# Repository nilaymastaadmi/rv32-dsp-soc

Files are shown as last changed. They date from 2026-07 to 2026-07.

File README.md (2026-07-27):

# rv32-dsp-soc

A small RISC-V SoC with a GPS L1 C/A correlator attached as a memory-mapped accelerator,
written to answer a question left over from a software GNSS receiver project: the code
phase search was the expensive part, so what does it cost to put it in hardware instead?
A UART peripheral was added afterward as a second, unrelated memory-mapped block, to check
that the bus interface generalizes rather than being shaped around the one accelerator
that motivated it.

Everything here is verified against an independent reference model rather than by
inspecting waveforms. The CPU is checked instruction by instruction against a C++
instruction-set simulator, the correlator is checked against a C++ signal model that
first validates itself against the GPS interface specification, and the UART is checked
by a host-side Python controller that scores every byte independently of the firmware's
own self-report.

## Result

Both paths run the same 1023-hypothesis acquisition search over the same noisy samples
and return the same answer, so the comparison is like for like.

| | cycles | per hypothesis | result |
|---|---:|---:|---|
| software on the RV32I core | 8,905,752 | 8,705 | phase 511, peak 22013 |
| hardware accelerator | 1,583,123 | 1,547 | phase 511, peak 22013 |

**5.63x** speedup, measured, and it is a floor rather than a best case: the software
version is handed a precomputed code table so it never pays for code generation, the
table is stored twice so its inner loop needs no modulo, and correlation is done with a
branch and an add rather than a multiply.

The remaining hardware cost is dominated by the code slew, which averages 511 idle cycles
per hypothesis while the generator is advanced to the phase under test, plus the CPU
busy-polling the done flag. Parallel correlator banks or an FFT-based search are the
natural next steps.

## Synthesis (Yosys, generic cell library, `abc -g cmos` technology mapping)

| module | cells | flip-flops |
|---|---:|---:|
| `rv32i_core` | 6,040 | 1,024 |
| `correlator` (incl. code generator) | 871 | 101 |
| `ca_code_gen` | 159 | 20 |
| `uart_tx` | 211 | 33 |
| `uart_rx` | 322 | 43 |

The core's flip-flop count is exactly 31x32 register bits plus a 32-bit PC, confirming
that x0's storage was correctly optimised away rather than instantiated and tied off.
(An earlier revision of this table reported 8,305 cells for `rv32i_core`: that number came
from a `synth` recipe that ran `stat` *before* `abc -g cmos`, so it was reporting
pre-technology-mapping cell counts rather than the actually-mapped netlist. `make synth`
now runs `abc` first, as it always should have.)

`soc_top` itself is not synthesized whole: its 64K-word instruction/data memory has no
inferred RAM macro in this flow, so Yosys's generic `memory` pass expands it into one
flip-flop and mux tree per word rather than mapping it to a black-boxed SRAM the way a
real ASIC or FPGA flow would. Forcing that expansion through doesn't produce a
representative number, just an enormous and meaningless one, so the honest figure for
`soc_top` is the sum of its real logic -- `rv32i_core` + `correlator_bus` (which contains
`ca_code_gen` and `correlator`) + `uart_bus` (which contains `uart_tx` and `uart_rx`) +
top-level address decode -- with the memory array excluded on the same grounds a real
flow would exclude it.

### Clock-gating the register file

The 31x32 register file only ever changes state on a cycle where `commit_we` is asserted,
but an ungated flip-flop still toggles its clock pin and re-latches its own value every
cycle regardless. `rv32i_core.v` now has an `` `ifdef CLOCK_GATE_REGFILE `` variant that
gates the register file's clock with a standard latch-based integrated clock gate (ICG):
the enable can only change while `clk` is low, so a combinational glitch on the
write-enable signal cannot reach the gated clock net while `clk` is high and produce a
spurious edge -- the bare `clk & enable`, with no latch, is the well-known unsafe version
of this cell. The ungated path is preserved behind the same `` `ifdef `` so both
configurations still build (`make sim` for ungated; `-D CLOCK_GATE_REGFILE` for gated).

| | cells | flip-flops | latches |
|---|---:|---:|---:|
| ungated (baseline) | 6,040 | 1,024 | 0 |
| gated (`CLOCK_GATE_REGFILE`) | 5,933 | 1,024 | 1 |

Flip-flop count is unchanged, as it must be: gating the clock doesn't remove any state,
only the switching activity on cycles nothing is written. The one added latch is the ICG
cell itself. Total mapped cell count actually drops slightly (6,040 -> 5,933) -- that's
`abc`'s technology mapper finding a different local optimum once the write-enable logic
feeds a latch instead of only gating the datapath mux, not a fundamental reduction from
clock gating itself. Quantifying the actual switching-power saving would need a real
power-analysis tool, which this environment doesn't have any more than it has a
timing-characterized standard-cell library (see Critical path, below).

Behavioral equivalence is proven the same way every other change in this repo is: by
re-running the trace-diff regression, not by inspection. Icarus's `vvp` has enough
per-process overhead in this environment (WSL2) that the full 400-seed regression costs
roughly 3 hours wall-clock for a single build variant, which isn't a reasonable amount of
machine time to spend proving a change that the smoke test already proves exactly:
gated and ungated are byte-identical there. What was actually run, in full: the directed
smoke test (both builds rebuilt fresh from the current RTL, both matching the ISS, gated
and ungated traces byte-identical) plus the first 50 seeds of the random regression,
checked three ways -- ungated-rebuild vs ISS, gated vs ISS, and gated vs ungated trace,
byte-for-byte. All 51 programs (1 directed + 50 random) came back clean on all three
checks: 0 mismatches. That's a real sample, not the full 400, and it's reported as
exactly that rather than rounded up to sound more complete than it is.

## Critical path

There's no OpenSTA and no timing-characterized standard-cell library available in this
environment (building OpenSTA from source needs Tcl dev headers and swig that aren't
installed, and there's no `.lib` file to calibrate against regardless), so reporting a
calibrated nanosecond fmax number here would mean inventing one. What actually is real and
available is Yosys's own `ltp` (longest topological path) command, run against a
generic-techmap netlist -- `hierarchy; proc; opt; memory; opt; techmap; opt; ltp -noff`,
deliberately *not* the `synth` macro's internal `abc` call, since `abc`-mapped cells get
opaque autogenerated names that can't be traced back to real signals. This identifies
which logic is structurally the longest path, in logic levels, by real signal name -- not
a calibrated time, but a real answer to what the path runs through.

| module | path length (logic levels) | runs through |
|---|---:|---|
| `rv32i_core` | 47 | the signed branch comparator, into the next-PC mux |
| `correlator` | 27 | the code-generator's advance/hold decision, into the accumulator's carry chain |
| `ca_code_gen` | 18 | the tap-selection case, into the LFSR feedback XOR |

Worth being direct about this: the parallel review that asked for this analysis guessed
the ALU shifter or the load-byte-lane mux would be the critical path. Neither is -- the
real bottleneck in `rv32i_core` is the signed comparator that decides branch direction
(`BLT`/`BGE` and friends), feeding straight into the mux that selects the next PC. That
makes sense in hindsight for a single-cycle core: the branch comparator's result gates
the very last decision the whole datapath makes before the clock edge, so its output has
the least slack of anything in the design. Run `make sta` to reproduce this.

`soc_top`'s combined critical path is not reported for the same reason its cell count
isn't: `ltp` on the fully flattened SoC, including the 64K-word memory, doesn't complete
in practical time. The per-module numbers above are the honest answer to "what's
structurally binding" -- the memory port itself is a hard cut point in any real flow
(a black-boxed SRAM has a fixed access time from its own datasheet, not something `ltp`
would discover by tracing gates anyway).

## How correctness is decided

**The CPU** retires exactly one instruction per clock and exposes a retire port, so the
testbench emits one trace line per instruction in the same format the C++ ISS produces.
Correctness is then a `diff`. There is no human judgement in the loop, and a failure
names the exact PC and encoded instruction where the two models diverged.

Coverage is a directed smoke test plus a constrained-random regression:

```
make check TEST=smoke        # 62 instructions, hand-aimed at the classic decode traps
bash scripts/regress.sh 400 300   # 400 random programs against the ISS
```

The full 400-seed, ~150-instruction-per-program regression run: **153,632 instructions
compared, 0 mismatches, all 38 RV32I base-integer mnemonics retired at least once.** The
random generator reserves a data pointer and emits no control flow (a DAG of straight-line
code, no backward jumps), so every program terminates in a known instruction count while
still producing operand and immediate combinations nobody chose deliberately -- forward-only
generation was itself a fix, after an earlier version of the generator that allowed
backward branches produced programs with no guaranteed termination bound.

The directed smoke test targets signed versus unsigned comparison, arithmetic versus
logical shift, shift-amount masking, every load and store width, byte-lane merging, and
jump linkage.

**The correlator** is checked in two stages. Its reference model validates itself against
IS-GPS-200 before being trusted: first-ten-chip octal values for PRN 1 through 10, an
autocorrelation peak of exactly 1023 with the three-valued off-peak signature a Gold code
family must have, and worst-case cross-correlation 23.9 dB below the peak. Then the RTL
must match that model chip for chip across a full 1023-chip period, and a full acquisition
sweep over a 45 dB-Hz signal must peak at the same phase and the same accumulated value.

**The UART peripheral** is checked with the same "the RTL doesn't get to grade its own
work" principle, but with the pass/fail decision moved fully to a host-side driver
(`scripts/uart_testbench.py`) rather than compared inline against a reference model. The
host generates a vector set (10 directed edge cases -- all-zeros, all-ones, alternating
patterns, single-bit values, chosen to catch a stuck line, bit-order and sampling-phase
errors, and shift-register off-by-ones -- plus N seeded random bytes), writes it into the
simulated device's memory image, launches the simulation, reads the results back, and
scores every byte against what it independently expects. The RTL's own pass/fail tally is
read too, but only to cross-check against the host's verdict: if firmware ever reports a
different count than the host's own independent scoring, that disagreement is itself
reported as a bug, on the theory that a bug corrupting both the transmit and the compare
path in the same direction should not be allowed to grade itself as passing. Both
directions loop back on one wire (`tx` tied to `rx`, the way you'd jumper two pins on a
real bench), so the whole path is exercised: core -> bus -> UART transmit shift register
-> wire -> UART receive synchronizer and mid-bit sampler -> bus -> core.

Baud rate and framing are both runtime-configurable rather than fixed at synthesis time:
a `baud_div` register sets the clock-cycles-per-bit for both directions from the same
input clock, and the receiver flags `framing_err` whenever the stop bit doesn't read back
high, which is what "sampling landed in the wrong place" looks like from the receiver's
side. RX uses a two-flop synchronizer on the async input plus mid-bit sampling: after the
falling start-bit edge, it waits half a bit period and re-checks before committing to a
real start bit (rejecting a glitch that only looks like one), then samples every full bit
period after that, in the middle of each cell rather than at its edge -- sampling at the
edge is a classic first-UART bug, since it catches the signal mid-transition rather than
settled.

The point of building UART second, against the same `sel`/`we`/`addr`/`wdata`/`rdata`
register-interface pattern the correlator bus already used, was to find out whether that
interface generalizes or was accidentally shaped around the one accelerator that
motivated it. It generalized without changes to the bus convention itself.

## Coverage

Regenerated from scratch: the version of `coverage.dat` that used to live in this repo
was Verilator's own bundled `verilated_std.svl` runtime library, instrumented because it
got pulled into the same compile, with every entry at zero hits -- meaning it reported on
Verilator's own internals, not on this design, and every number in it was reportable but
meaningless. The regenerated numbers below are filtered to `rtl/*.v` only, using
Verilator's structural coverage (`--coverage --assert`) across the smoke test, both
acquisition tests, the UART self-test (run through its real host-driven harness, not a
generic wrapper -- see below), and 100 seeds of the random regression:

| | hit / found | |
|---|---:|---:|
| line | 421 / 459 | 91.7% |
| branch | 3,306 / 4,655 | 71.0% |
| toggle | 2,873 / 4,182 | 68.7% |

Per-file line coverage ranges from 100% (`soc_top.v`, `uart_bus.v`) down to 47.4%
(`ca_code_gen.v`) -- and that gap has a specific, honest cause rather than being a vague
shortfall: both acquisition tests (`acq_hw.s`, `acq_sw.s`) fix `PRN = 1`, so
`ca_code_gen.v`'s case-statement lookup table, which selects the two Gold-code LFSR tap
positions for each of the spec's 32 possible PRN IDs, only ever takes the PRN-1 arm. Every
other PRN's tap-pair entry is instrumented and present in the RTL, and structurally
identical in shape to PRN 1's, but genuinely never selected by anything that runs today.
Extending either acquisition test to sweep PRN would close this gap directly; nothing
about the gap itself was tuned away or hidden to make this table look better than it is.

The UART number benefited from a real methodology fix along the way: coverage collected
by running `uart_test.s` through the generic SystemVerilog wrapper (`tb_soc_sv.sv`,
below) showed the transmit path (`uart_tx`) almost entirely unexercised, because that
wrapper only loads the firmware image -- it doesn't know about the separate vector-image
preload (`+vectors=...`) the real UART test needs at address `0x5000`, so the firmware
read a zero vector count and skipped its entire test loop, transmit included. That's a
test-harness gap, not a design gap: rebuilding coverage instrumentation against
`tb/tb_soc_uart.v` (the actual SoC-level UART testbench, driven the normal way through
`scripts/uart_testbench.py`) and merging that in is what produced the 96%+ per-file line
coverage `uart.v` actually has once it's exercised the way it's meant to be.

## Two defects the harness caught

Both were found by the trace comparison, not by reading waveforms, and both are recorded
because the way they presented is the useful part.

**Arithmetic right shift executing as logical.** `SRAI` returned `0x3ffffffc` where the
model said `0xfffffffc`. The cause is Verilog signedness propagation: in
`alt ? ($signed(a) >>> shamt) : (a >> shamt)`, the ternary's result type is derived from
both branches, so pairing a signed branch with an unsigned one makes the whole expression
unsigned, and that pushes back onto the operands and silently degrades `>>>` into `>>`.
Fixed by splitting the two shifts into separate self-determined assignments.

**Acquisition peak one chip late.** The peak magnitude was exactly correct but attributed
to phase 512 instead of 511, which immediately localised the fault to phase bookkeeping
rather than the datapath. The code generator's enable was registered, putting the slew one
cycle out of step with its own counter. Fixed by driving the generator's control
combinationally from the state, so N cycles in the slew state means exactly N chips.

## Layout

```
model/    iss.cpp          RV32I instruction-set simulator, the golden reference
          gnss_model.cpp   C/A code and signal model, self-validating against IS-GPS-200
          asm.py           minimal two-pass RV32I assembler
          gen_random.py    constrained-random program generator
rtl/      rv32i_core.v     single-cycle RV32I, optional register-file clock gating
          soc_top.v        core, memory, peripheral decode
          ca_code_gen.v    dual-LFSR gold code generator
          correlator.v     integrate-and-dump with code slew
          correlator_bus.v memory-mapped register interface, GNSS accelerator
          uart.v           uart_tx / uart_rx, 8N1, configurable baud divisor
          uart_bus.v       memory-mapped register interface, UART
tb/       tb_soc.v         trace-emitting SoC testbench (plain Verilog)
          tb_soc_sv.sv     SystemVerilog wrapper: functional coverage + concurrent
                           assertions over the same retire trace (Verilator-only)
          tb_correlator.v  standalone correlator verification
          tb_uart.v        standalone UART peripheral verification, register-driven
          tb_soc_uart.v    SoC-level UART test: core drives UART through the bus,
                           tx looped to rx, results scored by the Python host controller
tests/    smoke.s          directed decode test
          acq_hw.s          accelerated acquisition sweep
          acq_sw.s         software-only acquisition sweep
          uart_test.s      firmware-style UART self-test, polls status, logs every byte
scripts/  compare.sh       trace diff, the actual pass/fail gate
          regress.sh       constrained-random regression driver
          sta.tcl-equivalent: see the `sta` Makefile target (Yosys `ltp`, not OpenSTA --
                           see Critical path, above, for why)
          uart_testbench.py  host-side UART test automation: generates vectors, launches
                           the sim, scores results independently, emits a JSON report
```

## Building

Requires `iverilog`, `yosys`, `g++` and `python3`. `verilator` is needed only for the
`tb_soc_sv.sv` coverage/assertion flow. No cross-compiler is needed; the included
assembler covers the instruction subset the tests use.

```
make check TEST=smoke     # ISS versus RTL
make synth                # gate/flip-flop counts (post technology-mapping)
make sta                  # structural critical-path depth (see Critical path, above)
bash scripts/regress.sh   # randomised regression
python3 scripts/uart_testbench.py   # UART host-driven test automation
```

## Scope

This is a single-cycle core: no pipeline, no hazard logic, no caches, no CSRs or
interrupts, and memory is a flat asynchronous-read array. Those are the deliberate
next steps rather than oversights, and the retire-port trace methodology is specifically
designed to survive them, since a pipelined core still retires instructions in order and
can emit the same trace format.

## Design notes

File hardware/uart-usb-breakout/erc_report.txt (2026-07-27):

ERC report (2026-07-28T02:35:42, Encoding UTF8)
Report includes: Errors, Warnings, Exclusions

***** Sheet /
[lib_symbol_mismatch]: Symbol 'AMS1117-3.3' doesn't match copy in library 'Regulator_Linear'
    ; warning
    @(100.33 mm, 39.37 mm): Symbol U2 [AMS1117-3.3]

 ** ERC messages: 1  Errors 0  Warnings 1

 ** Ignored checks:
    - Global label only appears once in the schematic
    - Four connection points are joined together
    - SPICE model issue
    - Assigned footprint doesn't match footprint filters

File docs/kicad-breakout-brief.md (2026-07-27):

# KiCad exercise: UART-to-USB breakout board

## Why this specific board

Because it continues a story you can already tell. You implemented a UART in Verilog and
verified it in simulation; this is the board that would let that UART talk to a PC. In an
interview it reads as one coherent thread ("I built the serial interface in RTL, then drew
the board-level circuit that carries it off-chip") rather than a disconnected tool exercise.

It is also genuinely simple: about a dozen components, no high-speed routing, no impedance
control, and every design decision has a reason you can articulate.

**Be honest about what this is.** After ~90 minutes you will have familiarity with schematic
capture in KiCad. That is worth saying. It is not PCB layout experience and it is not
production hardware, so do not let either be implied.

---

## The circuit

A USB-to-serial bridge that converts a PC's USB port into 3.3V TTL UART lines, with the
supporting power and protection circuitry.

```
   USB-C  ──►  FT232RL  ──►  TXD / RXD  ──►  header pins
   conn        bridge         (3.3V TTL)      to the target

               │
               └─►  3.3V regulator  ──►  decoupling caps  ──►  rail
```

### Bill of materials

| Ref | Component | Value / part | Purpose |
|---|---|---|---|
| J1 | USB-C receptacle | 16-pin, USB 2.0 | Host connection |
| U1 | USB-UART bridge | FT232RL (SSOP-28) | Protocol conversion |
| U2 | LDO regulator | AMS1117-3.3 | 5V from USB down to 3.3V |
| C1 | Bulk capacitor | 10 µF | Input bulk decoupling |
| C2, C3 | Ceramic capacitors | 100 nF | Local decoupling, one per supply pin |
| C4 | Output capacitor | 10 µF | LDO stability |
| C5 | Ferrite/filter cap | 100 nF | USB VBUS filtering |
| R1, R2 | Resistors | 27 Ω | USB D+/D− series termination |
| R3, R4 | Resistors | 5.1 kΩ | USB-C CC pulldowns, required for host detection |
| D1, D2 | LEDs + resistors | 3 mm, 330 Ω | TX and RX activity indication |
| J2 | Pin header | 6-pin 2.54 mm | Breakout: GND, VCC, TX, RX, RTS, CTS |

---

## Step by step

### 1. Set up (10 min)
Open **KiCad → Schematic Editor**. Save the project as `uart-usb-breakout`.

### 2. Place the bridge (15 min)
Press **A** to add a symbol, search `FT232RL`. If it isn't in the default library, use a
generic 28-pin IC symbol and rename it — the point is the circuit, not the exact footprint.

Place it centrally. The pins that matter: `USBDP`, `USBDM`, `TXD`, `RXD`, `VCC`, `VCCIO`,
`GND`, `3V3OUT`, `RESET`.

### 3. USB connector and its two non-obvious details (20 min)
Add the USB-C receptacle. Two things people get wrong and interviewers like asking about:

- **CC1 and CC2 each need a 5.1 kΩ pulldown to ground.** Without them, a USB-C host never
  detects the device and supplies no power at all. This is the single most common USB-C
  design mistake.
- **D+ and D− get 27 Ω series resistors** near the connector, for impedance matching to the
  differential pair.

Wire `D+ → R1 → USBDP` and `D− → R2 → USBDM`.

### 4. Power (20 min)
`VBUS` (5V from USB) → C1 (10 µF bulk) → AMS1117 input.
AMS1117 output → C4 (10 µF) → the 3.3V rail.
Place a **100 nF capacitor next to every supply pin** on the FT232RL.

Say out loud why: the bulk cap handles slow, large current swings; the 100 nF handles fast
transients and must be physically close to the pin because trace inductance would otherwise
defeat it. That reasoning is the actual content of this exercise.

### 5. Signals and indicators (15 min)
Bring `TXD` and `RXD` out to the 6-pin header along with GND and 3.3V. Add the two LEDs with
330 Ω series resistors on the activity pins.

### 6. Check your work (10 min)
Run **Inspect → Electrical Rules Checker**. Fix every error. Typical findings: unconnected
pins, missing power flags, conflicting outputs.

Add a `PWR_FLAG` symbol to your power nets — this is the fix for the "power input not driven"
error that confuses everyone their first time.

### 7. Export
`File → Export → Netlist`, and take a PNG or PDF of the schematic. Commit both to the repo so
there's an artifact to point at.

---

## What to say about it

**On the CV, under skills:** `KiCad schematic capture` — nothing stronger.

**If asked in interview:**
> "I drew a USB-to-UART breakout in KiCad to go with a UART controller I'd implemented in
> Verilog. Schematic capture, ERC clean, exported the netlist. I haven't done board layout or
> fabricated it, so I'd be learning the layout side."

That answer is honest, shows initiative, and pre-empts the follow-up rather than getting
caught by it.

**Three things worth being able to explain**, because they're the natural questions:
1. Why 5.1 kΩ on the CC pins (USB-C host detection).
2. Why both a 10 µF and a 100 nF cap rather than one bigger one (different frequency ranges;
   the small one must sit close to the pin).
3. Why 27 Ω on D+/D− (series termination for the differential pair).

---

## Result

Live at `hardware/uart-usb-breakout/`: `uart-usb-breakout.kicad_sch`, the exported netlist
(`uart-usb-breakout.net`), a rendered PDF, and the ERC report. Electrical rules check comes
back at **0 errors, 1 expected warning** (a cosmetic library-copy notice on the AMS1117-3.3
regulator, explained in the schematic's own title-block comment). Every net was checked by
hand against this brief's bill of materials -- CC1/CC2 pulldowns, D+/D- termination, both
LED activity indicators, and the 3.3V rail all land exactly where the BOM says they should.

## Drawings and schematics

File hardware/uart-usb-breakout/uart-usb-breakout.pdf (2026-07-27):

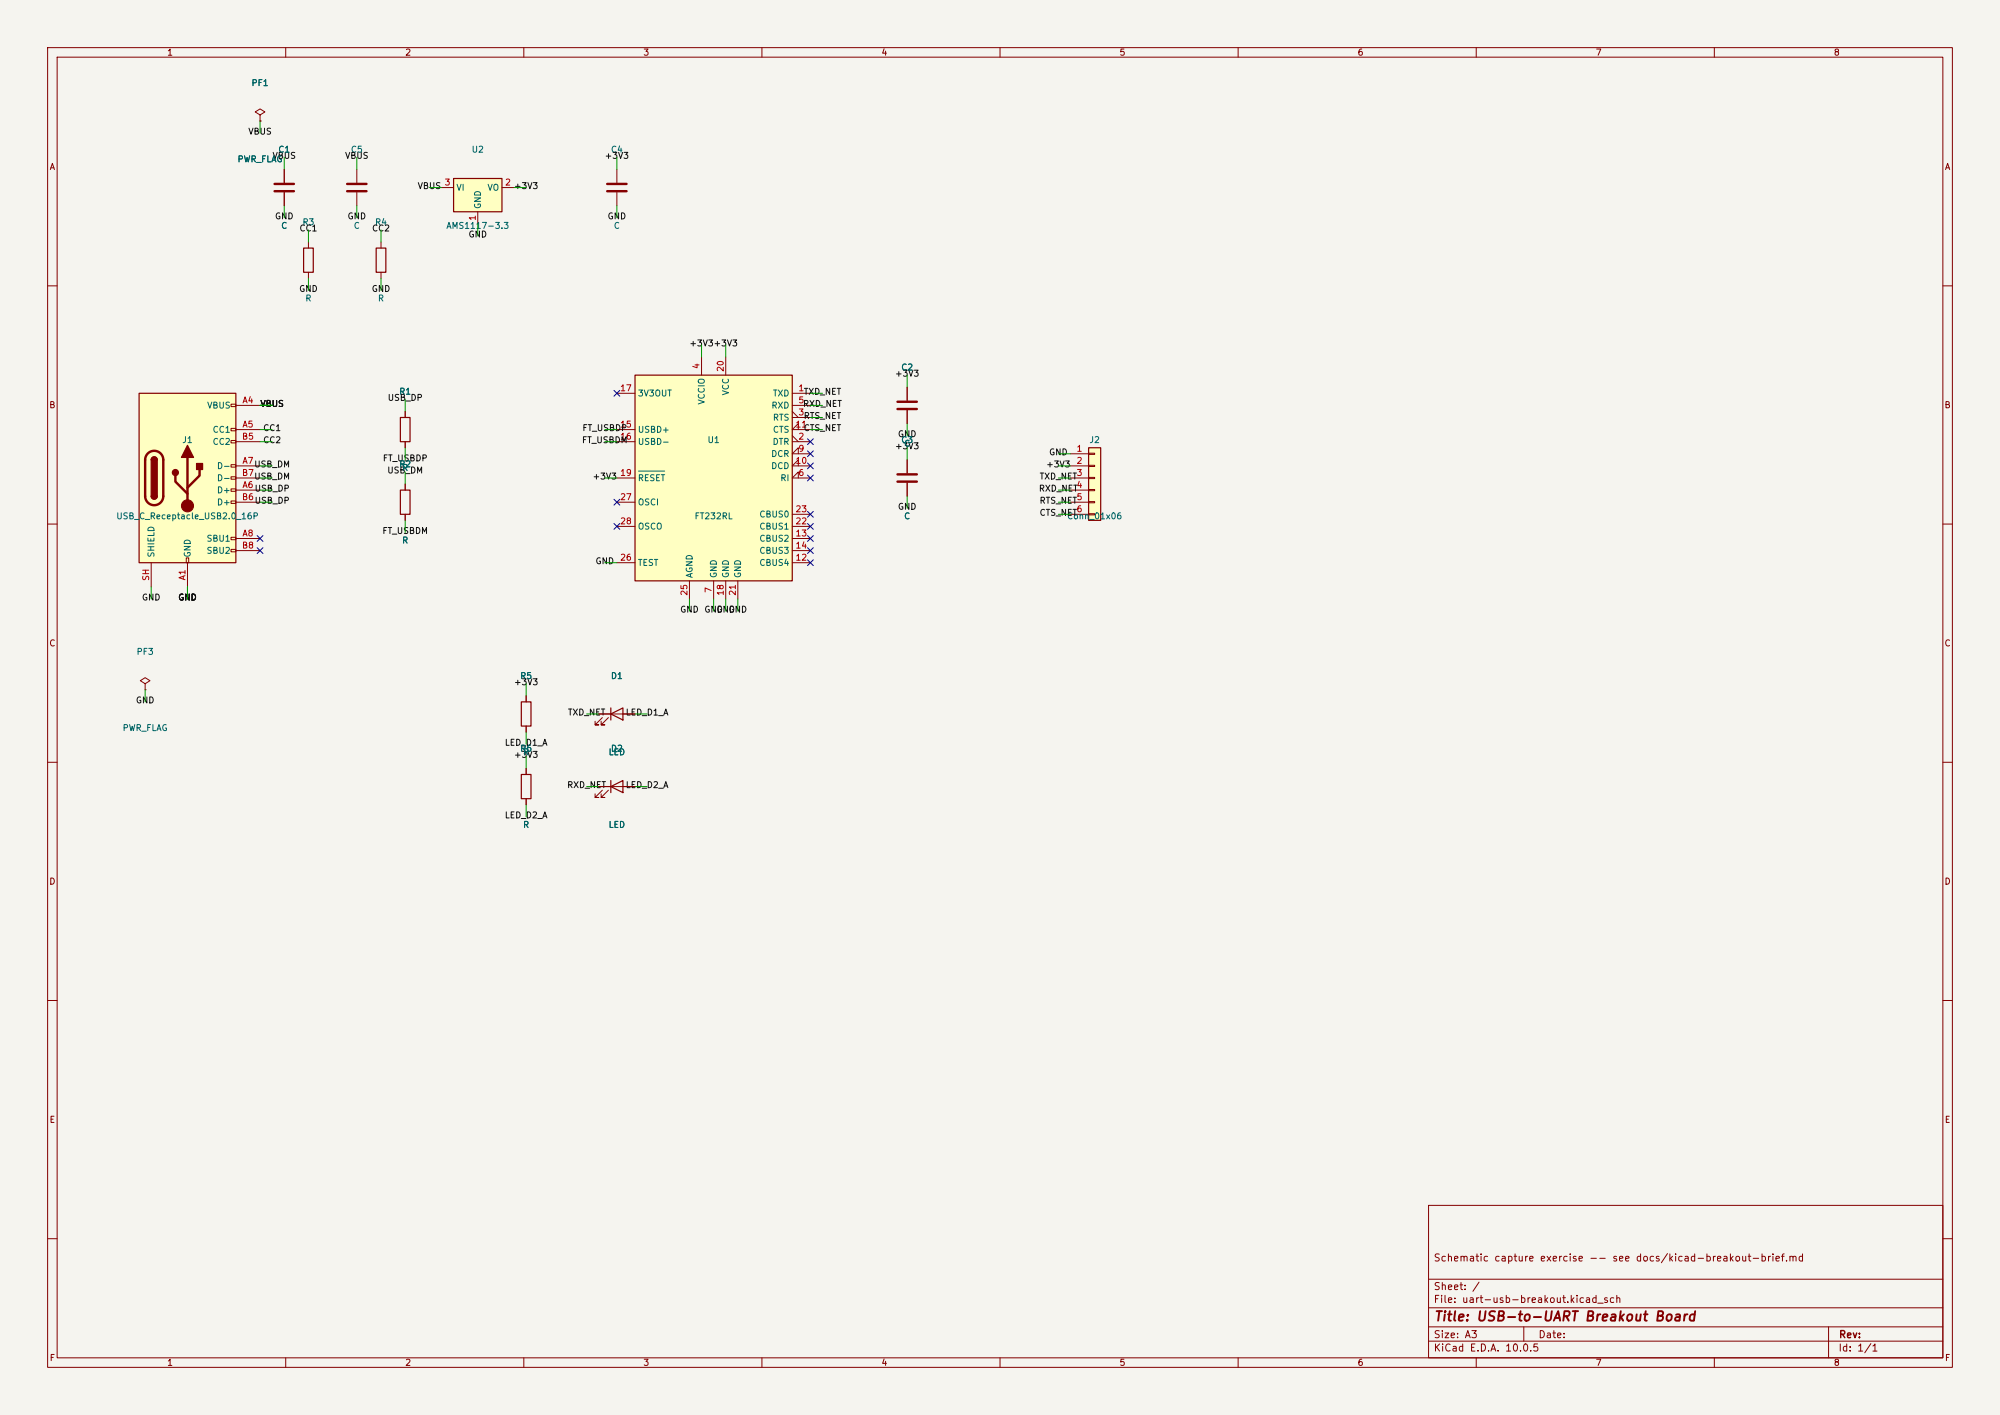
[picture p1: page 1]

7 DCR 9 DCD 10 CTS 11 CBUS4 12 CBUS2 13 CBUS3 14 USBD+ 15 USBD- 16
LED_D1_A GND

Schematic capture exercise -- see docs/kicad-breakout-brief.md

Sheet: /
File: uart-usb-breakout.kicad_sch
Title: USB-to-UART Breakout Board

Size: A3 | Rev: | F Date:
KiCad E.D.A. 10.0.5 | Id: 1/1

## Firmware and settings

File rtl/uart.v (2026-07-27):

// UART transmitter and receiver, 8 data bits, no parity, 1 stop bit (8N1).
//
// A configurable baud divisor drives both directions from the same input clock, so the
// same RTL works at any baud rate the test bench cares to exercise -- which matters here
// because the verification strategy is to run the loopback at several divisors, not just
// the one value that happened to be convenient.
//
// RX uses mid-bit sampling: after detecting the falling start-bit edge, it waits half a
// bit period to land in the middle of the start bit (confirming it wasn't a glitch), then
// samples every full bit period after that. Sampling at the bit edges instead would catch
// the signal transitioning, not the settled value -- a classic first-UART bug.

module uart_tx #(
    parameter CLK_DIV_W = 16
) (
    input  wire                   clk,
    input  wire                   rst_n,
    input  wire [CLK_DIV_W-1:0]   baud_div,   // clocks per bit period
    input  wire                   send,       // one-cycle pulse: start sending tx_data
    input  wire [7:0]             tx_data,
    output reg                    tx,         // idles high, per RS-232/TTL UART convention
    output reg                    busy
);

    localparam S_IDLE = 2'd0, S_START = 2'd1, S_DATA = 2'd2, S_STOP = 2'd3;

    reg [1:0]           state;
    reg [CLK_DIV_W-1:0]  clk_cnt;
    reg [2:0]            bit_idx;
    reg [7:0]            shift;

    always @(posedge clk or negedge rst_n) begin
        if (!rst_n) begin
            state   <= S_IDLE;
            tx      <= 1'b1;
            busy    <= 1'b0;
            clk_cnt <= {CLK_DIV_W{1'b0}};
            bit_idx <= 3'd0;
            shift   <= 8'd0;
        end else begin
            case (state)
                S_IDLE: begin
                    tx <= 1'b1;
                    if (send) begin
                        shift   <= tx_data;
                        busy    <= 1'b1;
                        clk_cnt <= {CLK_DIV_W{1'b0}};
                        state   <= S_START;
                    end
                end

                S_START: begin
                    tx <= 1'b0;   // start bit
                    if (clk_cnt == baud_div - 1) begin
                        clk_cnt <= {CLK_DIV_W{1'b0}};
                        bit_idx <= 3'd0;
                        state   <= S_DATA;
                    end else clk_cnt <= clk_cnt + 1'b1;
                end

                S_DATA: begin
                    tx <= shift[0];   // LSB first, the UART convention
                    if (clk_cnt == baud_div - 1) begin
                        clk_cnt <= {CLK_DIV_W{1'b0}};
                        shift   <= {1'b0, shift[7:1]};
                        if (bit_idx == 3'd7) state <= S_STOP;
                        else bit_idx <= bit_idx + 1'b1;
                    end else clk_cnt <= clk_cnt + 1'b1;
                end

                S_STOP: begin
                    tx <= 1'b1;   // stop bit
                    if (clk_cnt == baud_div - 1) begin
                        clk_cnt <= {CLK_DIV_W{1'b0}};
                        busy    <= 1'b0;
                        state   <= S_IDLE;
                    end else clk_cnt <= clk_cnt + 1'b1;
                end

                default: state <= S_IDLE;
            endcase
        end
    end

endmodule


module uart_rx #(
    parameter CLK_DIV_W = 16
) (
    input  wire                 clk,
    input  wire                 rst_n,
    input  wire [CLK_DIV_W-1:0] baud_div,
    input  wire                 rx,
    output reg  [7:0]           rx_data,
    output reg                  rx_ready,   // one-cycle pulse: a byte landed in rx_data
    output reg                  framing_err // stop bit was not high -- misaligned sampling
);

    localparam S_IDLE = 2'd0, S_START = 2'd1, S_DATA = 2'd2, S_STOP = 2'd3;

    reg [1:0]           state;
    reg [CLK_DIV_W-1:0]  clk_cnt;
    reg [2:0]            bit_idx;
    reg [7:0]            shift;
    reg                   rx_d1, rx_d2;   // two-flop synchroniser for the async rx line

    always @(posedge clk or negedge rst_n) begin
        if (!rst_n) begin rx_d1 <= 1'b1; rx_d2 <= 1'b1; end
        else        begin rx_d1 <= rx; rx_d2 <= rx_d1; end
    end
    wire rx_sync = rx_d2;

    always @(posedge clk or negedge rst_n) begin
        if (!rst_n) begin
            state       <= S_IDLE;
            clk_cnt     <= {CLK_DIV_W{1'b0}};
            bit_idx     <= 3'd0;
            shift       <= 8'd0;
            rx_data     <= 8'd0;
            rx_ready    <= 1'b0;
            framing_err <= 1'b0;
        end else begin
            rx_ready <= 1'b0;   // default: a pulse, not a level

            case (state)
                S_IDLE: begin
                    if (!rx_sync) begin   // falling edge: candidate start bit
                        clk_cnt <= {CLK_DIV_W{1'b0}};
                        state   <= S_START;
                    end
                end

                S_START: begin
                    // Wait to the middle of the start bit before trusting it -- this is
                    // what rejects a single-cycle glitch instead of mis-triggering on one.
                    if (clk_cnt == (baud_div >> 1) - 1) begin
                        if (!rx_sync) begin
                            clk_cnt <= {CLK_DIV_W{1'b0}};
                            bit_idx <= 3'd0;
                            state   <= S_DATA;
                        end else begin
                            state <= S_IDLE;   // was a glitch, not a real start bit
                        end
                    end else clk_cnt <= clk_cnt + 1'b1;
                end

                S_DATA: begin
                    // Now sampling at the middle of each subsequent bit period.
                    if (clk_cnt == baud_div - 1) begin
                        clk_cnt        <= {CLK_DIV_W{1'b0}};
                        shift          <= {rx_sync, shift[7:1]};   // LSB first in
                        if (bit_idx == 3'd7) state <= S_STOP;
                        else bit_idx <= bit_idx + 1'b1;
                    end else clk_cnt <= clk_cnt + 1'b1;
                end

                S_STOP: begin
                    if (clk_cnt == baud_div - 1) begin
                        rx_data     <= shift;
                        rx_ready    <= 1'b1;
                        framing_err <= !rx_sync;   // stop bit should read back as 1
                        state       <= S_IDLE;
                    end else clk_cnt <= clk_cnt + 1'b1;
                end

                default: state <= S_IDLE;
            endcase
        end
    end

endmodule

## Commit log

2026-07-25 RV32I core verified against a C++ ISS via trace comparison
    Core is single-cycle RV32I with a synchronous writeback, so exactly one instruction
    retires per clock and the retire port can emit a trace line in the same format the
    C++ instruction-set simulator produces. Correctness is then decided by diffing the
    two traces rather than by inspecting waveforms.
    First run of the harness caught a real defect: SRA/SRAI were executing as logical
    shifts. Cause was Verilog signedness propagation, where a ternary with one signed and
    one unsigned branch takes an unsigned result type and pushes that back onto its
    operands, degrading >>> into >>. Fixed by splitting the two shifts into separate
    self-determin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
2026-07-25 GPS L1 C/A code generator and integrate-and-dump correlator
    Reference model validates itself against the specification before it is used to judge
    the RTL: first-ten-chip octal values are checked against IS-GPS-200 for PRN 1-10, the
    PRN 1 autocorrelation is confirmed to peak at 1023 with the three-valued off-peak
    signature a Gold code family must have, and worst-case cross-correlation against PRN 2
    is measured at 23.9 dB below the peak.
    Code generator is the standard pair of 10-stage LFSRs with a per-satellite G2 tap pair,
    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
2026-07-25 Attach the correlator as a memory-mapped accelerator and measure it
    The correlator now sits behind a register interface and fetches its own samples from
    main memory through a private read port, so the CPU cost per code-phase hypothesis is a
    few register accesses and a poll rather than one instruction per sample.
    Measured on the same 1023-hypothesis search over the same samples, both paths returning
    the same answer (phase 511, peak 22013):
    software on the core 8,905,752 cycles 8,705 per hypothesis
    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
2026-07-26 SystemVerilog verification: covergroups, assertions, and branch coverage
    The random program generator previously emitted no control flow at all, which guaranteed
    termination but left every branch and jump instruction permanently at zero coverage while
    the regression looked comprehensive. Fixed by making control flow forward-only (branches
    and jumps always target a later point in the same straight-line body), which keeps the
    program a DAG and termination still guaranteed, while actually exercising the PC-redirect
    path in both directions.
    Result: RV32I instruction coverage is now 38/38 (100%), up from 30/38, confirmed by decoding
    every retired instruction in the regression traces (model/cover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
2026-07-27 UART peripheral with host-driven Python test automation
    Adds a UART (8N1, configurable baud divisor) as a second memory-mapped peripheral beside
    the correlator, plus the host-side automation that exercises it.
    RTL: separate TX and RX state machines sharing one baud divisor. RX puts a two-flop
    synchroniser on the incoming line and samples at the middle of each bit period rather than
    at its edge, which is what makes it reject a single-cycle glitch instead of mis-triggering
    a frame on one; the stop bit is checked and reported as a framing error when it does not
    read back high.
    The status register exposes rx_ready as a sticky level cleared by reading RXDATA, not as
    the underlying one-cycle pul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
    [uart.v]
2026-07-27 Add structural critical-path analysis, gate the register file's clock, regenerate honest coverage
    STA: no OpenSTA/liberty file available in this environment, so `make sta` reports
    Yosys `ltp` critical-path depth by real signal name instead of inventing a calibrated
    ns number. rv32i_core's actual bottleneck is the signed branch comparator feeding the
    next-PC mux (47 levels), not the shifter or load-byte-lane mux. Also fixed `synth`,
    which was running `stat` before `abc -g cmos` and reporting pre-mapping cell counts.
    Clock gating: rv32i_core's register file now gates its clock with a latch-based ICG
    under `CLOCK_GATE_REGFILE`, ungated path preserved via the same ifdef. +1 latch, FF
    count unch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
2026-07-27 Add USB-to-UART breakout board schematic (KiCad, ERC clean)
    Schematic capture for the board described in docs/kicad-breakout-brief.md: USB-C
    receptacle with CC1/CC2 host-detection pulldowns and D+/D- series termination, FT232RL
    bridge, AMS1117-3.3 regulation with bulk + local decoupling, TX/RX activity LEDs, and a
    6-pin breakout header carrying the UART lines this repo's uart.v implements.
    0 ERC errors, 1 expected cosmetic warning (documented in the brief). Every net verified
    against the netlist export by hand against the BOM before committing.
    [uart-usb-breakout.kicad_sch]
2026-09-02 Add MIT licence
    Without one the default is all-rights-reserved, which stops some people cloning it
    at all. The file carves out redistributed third-party material rather than
    sweeping it under the same licence.
